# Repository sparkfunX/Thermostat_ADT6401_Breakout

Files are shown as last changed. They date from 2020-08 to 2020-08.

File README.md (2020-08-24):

SparkFun Auto-Digital Thermostat - ADT6401
=============================

ADT6401 (https://cdn.sparkfun.com/assets/parts/1/5/6/6/5/16772-Auto-Digital_Thermostat_-_ADT6401-01.jpg)

New from SparkX, the ADT6401 breakout board. This IC triggers alarm pin and LED when the temperature reading crosses a temperature trip point. Set the trip point easily using the SPDT switches included on the breakout.

SparkFun labored with love to design this board. Feel like supporting open-source hardware?
Buy a [board](https://www.sparkfun.com/) from SparkFun!

Repository Contents
-------------------

* **/Documents** - Datasheet for the ADT6401 IC.
* **/Hardware** - Eagle design files (.brd, .sch).
* **/Production** - Production panel files (.brd).

License Information
-------------------

This product is _**open source**_!

Please review the LICENSE.md file for license information.

If you have any questions or concerns regarding our licensing, please contact technical support on our [SparkFun Forum](https://www.sparkfun.com/viewforum.php?f=152).

Distributed as-is; no warranty is given.

- Your friends at SparkFun

_<COLLABORATION CREDIT>_

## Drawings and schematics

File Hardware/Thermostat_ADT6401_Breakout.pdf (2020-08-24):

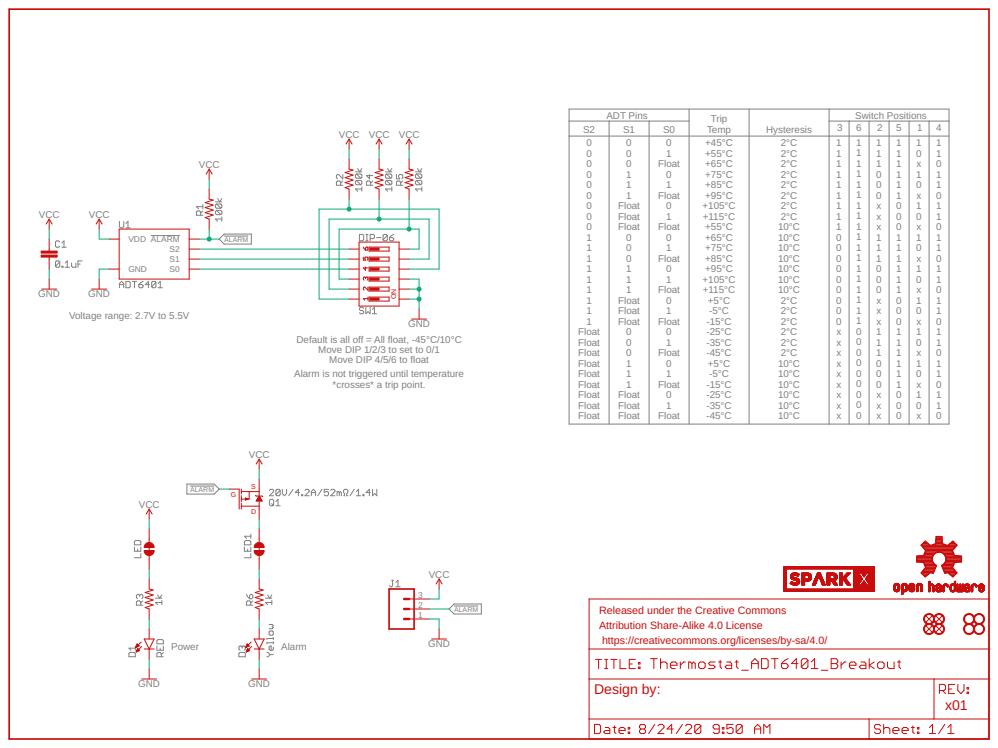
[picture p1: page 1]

ADT Pins | Trip Temp | Hysteresis
S2 | S1 | S0

Default is all off = All float, -45°C/10°C
Move DIP 1/2/3 to set to 0/1
Move DIP 4/5/6 to float

Alarm is not triggered until temperature

Released under the Creative Commons Attribution Share-Alike 4.0 License

https://creativecommons.org/licenses/by-sa/4.0/

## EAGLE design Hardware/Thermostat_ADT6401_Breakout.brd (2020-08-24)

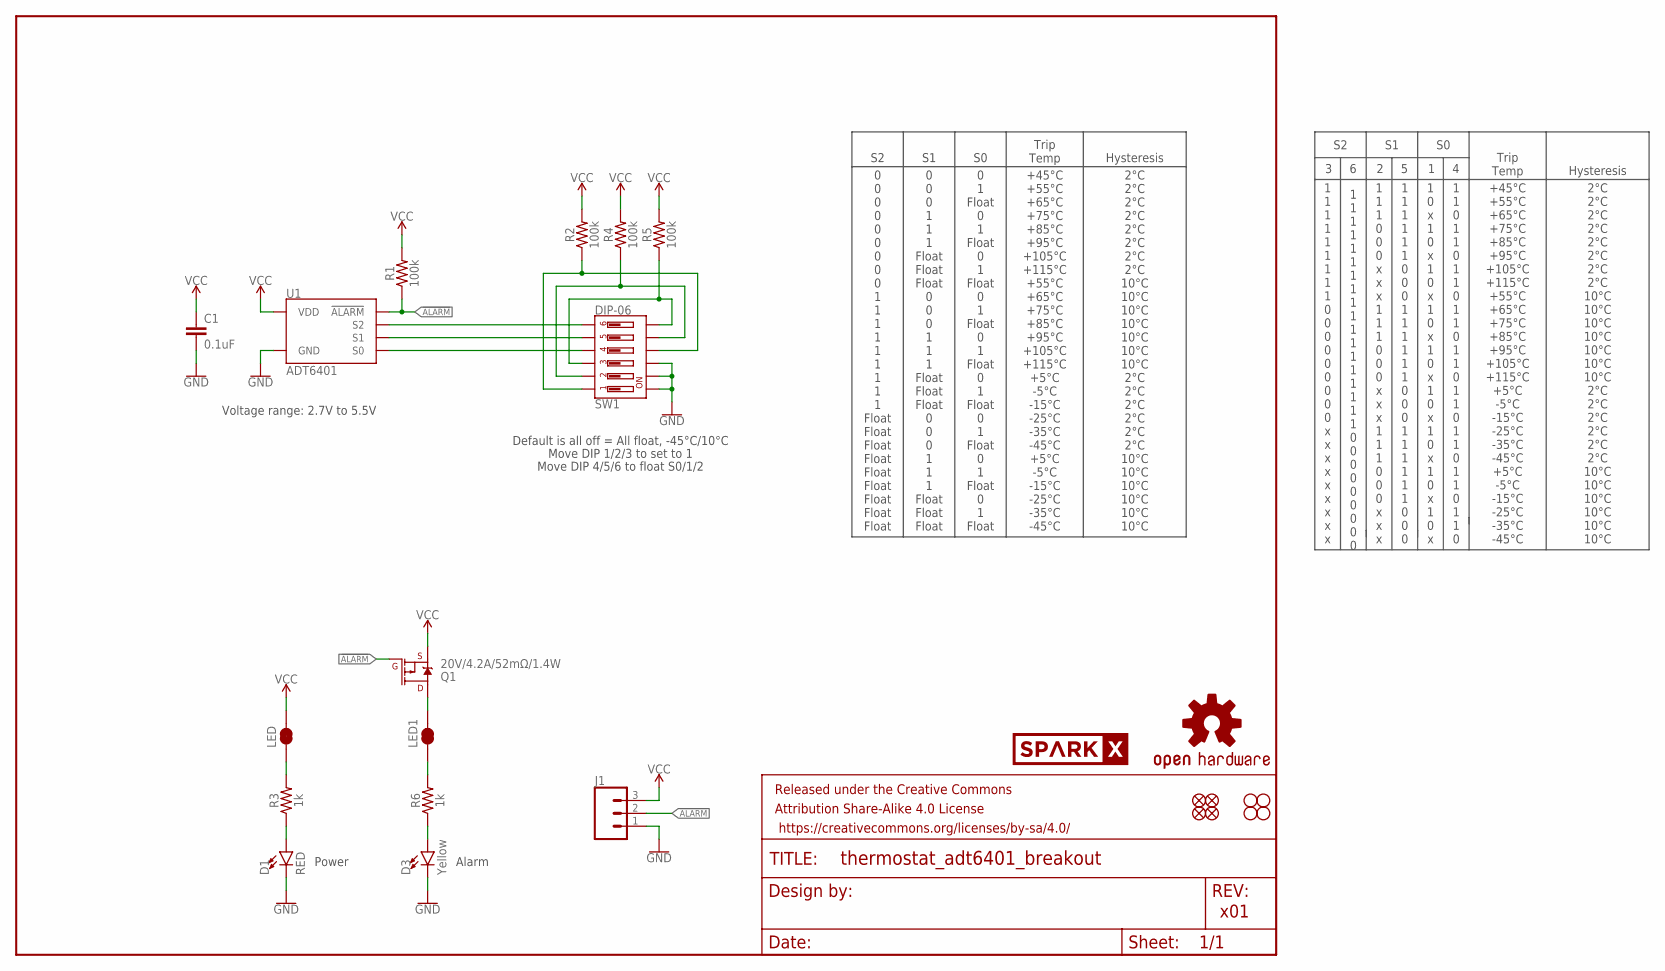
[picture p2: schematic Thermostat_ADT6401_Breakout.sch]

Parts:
C1: 0.1uF; 0603
D1: RED; LED-0603
D3: Yellow; LED-0603
FRAME1: FRAME-LETTER; CREATIVE_COMMONS
J1: CONN_031X03_NO_SILK; 1X03_NO_SILK
JP1, JP2, JP5, JP6: FIDUCIAL1X2; FIDUCIAL-1X2
JP3, JP4, JP8, JP9: STAND-OFF
LED, LED1: JUMPER-SMT_2_NC_TRACE_SILK; SMT-JUMPER_2_NC_TRACE_SILK
LOGO1: OSHW-LOGOMINI; OSHW-LOGO-MINI
Q1: 20V/4.2A/52mΩ/1.4W; SOT23-3
R1, R2, R4, R5: 100k; 0603
R3, R6: 1k; 0603
SW1: DIP-06; DIPSWITCH-06-SMD
U1: ADT6401; SOT23-6
U$1: SPARKX-LOGO4; SPARKX-MEDIUM

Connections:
!ALARM!: J1.2, Q1.1 (G), R1.1, U1.6 (!ALARM!)
GND: C1.2, D1.C, D3.C, J1.1, SW1.10, SW1.11, SW1.12, U1.5 (GND)
unnamed: D1.A, R3.1
unnamed: LED.1, R3.2
unnamed: LED1.2, Q1.3 (D)
unnamed: D3.A, R6.1
unnamed: LED1.1, R6.2
S0: SW1.4, U1.3 (S0)
S0_PU: R2.1, SW1.1, SW1.9
S1: SW1.5, U1.2 (S1)
S1_PU: R4.1, SW1.2, SW1.8
S2: SW1.6, U1.1 (S2)
S2_PU: R5.1, SW1.3, SW1.7
VCC: C1.1, J1.3, LED.2, Q1.2 (S), R1.2, R2.2, R4.2, R5.2, U1.4 (VDD)

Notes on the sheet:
x01
Power
Move DIP 4/5/6 to float S0/1/2
0 0 0 0 0 0 0 0 0 1 1 1 1 1 1 1 1 1 Float Float Float Float Float Float Float Float Float
+45°C +55°C +65°C +75°C +85°C +95°C +105°C +115°C +55°C +65°C +75°C +85°C +95°C +105°C +115°C +5°C -5°C -15°C -25°C -35°C -45°C +5°C -5°C -15°C -25°C -35°C -45°C
0 0 0 1 1 1 Float Float Float 0 0 0 1 1 1 Float Float Float 0 0 0 1 1 1 Float Float Float
0 1 Float 0 1 Float 0 1 Float 0 1 Float 0 1 Float 0 1 Float 0 1 Float 0 1 Float 0 1 Float
2°C 2°C 2°C 2°C 2°C 2°C 2°C 2°C 10°C 10°C 10°C 10°C 10°C 10°C 10°C 2°C 2°C 2°C 2°C 2°C 2°C 10°C 10°C 10°C 10°C 10°C 10°C
Trip Temp
Hysteresis
Move DIP 1/2/3 to set to 1
Default is all off = All float, -45°C/10°C
Alarm
Voltage range: 2.7V to 5.5V
1 1 0 1 1 0 1 1 0 1 1 0 1 1 0 1 1 0 1 1 0 1 1 0 1 1 0
1 0 x 1 0 x 1 0 x 1 0 x 1 0 x 1 0 x 1 0 x 1 0 x 1 0 x
1 1 1 1 1 1 0 0 0 1 1 1 1 1 1 0 0 0 1 1 1 1 1 1 0 0 0
1 1 1 0 0 0 x x x 1 1 1 0 0 0 x x x 1 1 1 0 0 0 x x x
1 1 1 1 1 1 1 1 1 1 1 1 1 1 1 1 1 1 0 0 0 0 0 0 0 0 0
1 1 1 1 1 1 1 1 1 0 0 0 0 0 0 0 0 0 x x x x x x x x x

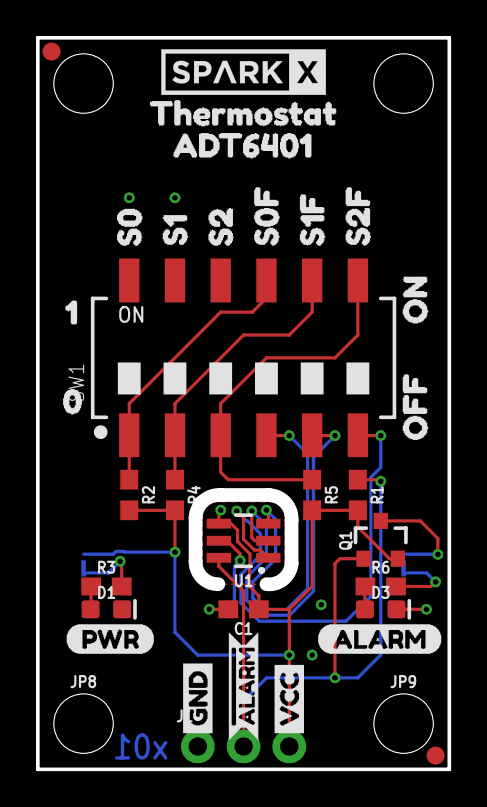
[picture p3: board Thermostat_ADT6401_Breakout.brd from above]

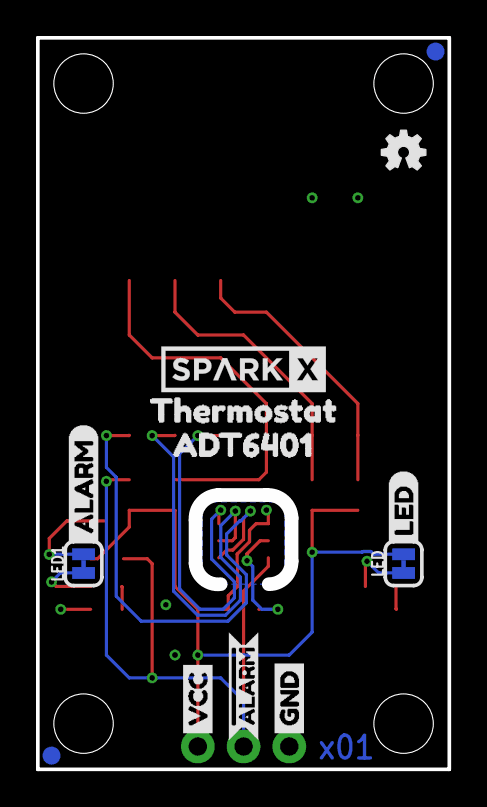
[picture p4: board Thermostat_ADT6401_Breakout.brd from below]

Board: 2 copper layers, 22.9 x 40.6 mm, 52 parts (13 on the bottom side), 14 nets.

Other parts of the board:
U$2: 01
U$3, U$15: #ALARM6
U$4, U$12: ADT64012
U$5, U$13: GND6
U$6: OFF3
U$7: ON2
U$8: 10
U$9, U$19: THERMOSTAT0
U$10: (PWR)
U$11, U$16: VCC5
U$14: S1F5
U$17: SPARKX-LOGO4; SPARKX-MEDIUM
U$18: ORDERING_INSTRUCTIONS
U$20: ALARM1
U$21: S2F7
U$22: S12
U$23: S23
U$24: S00
U$25: S0F1
U$26: LED0
U$27: ALARM2

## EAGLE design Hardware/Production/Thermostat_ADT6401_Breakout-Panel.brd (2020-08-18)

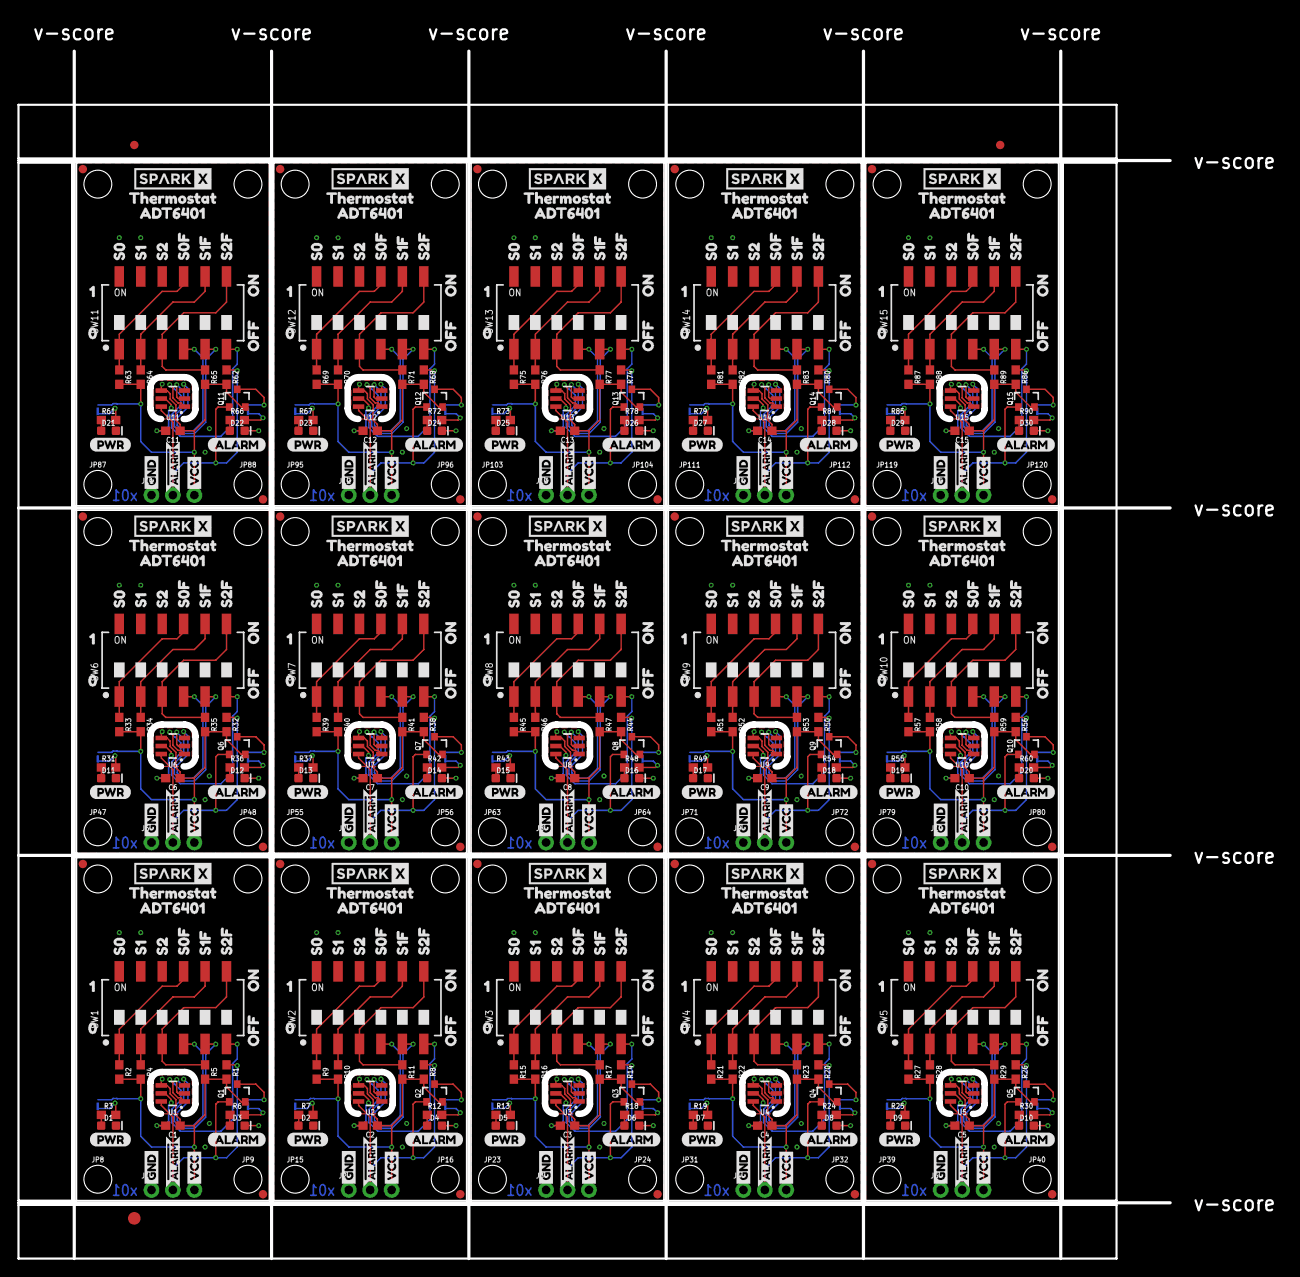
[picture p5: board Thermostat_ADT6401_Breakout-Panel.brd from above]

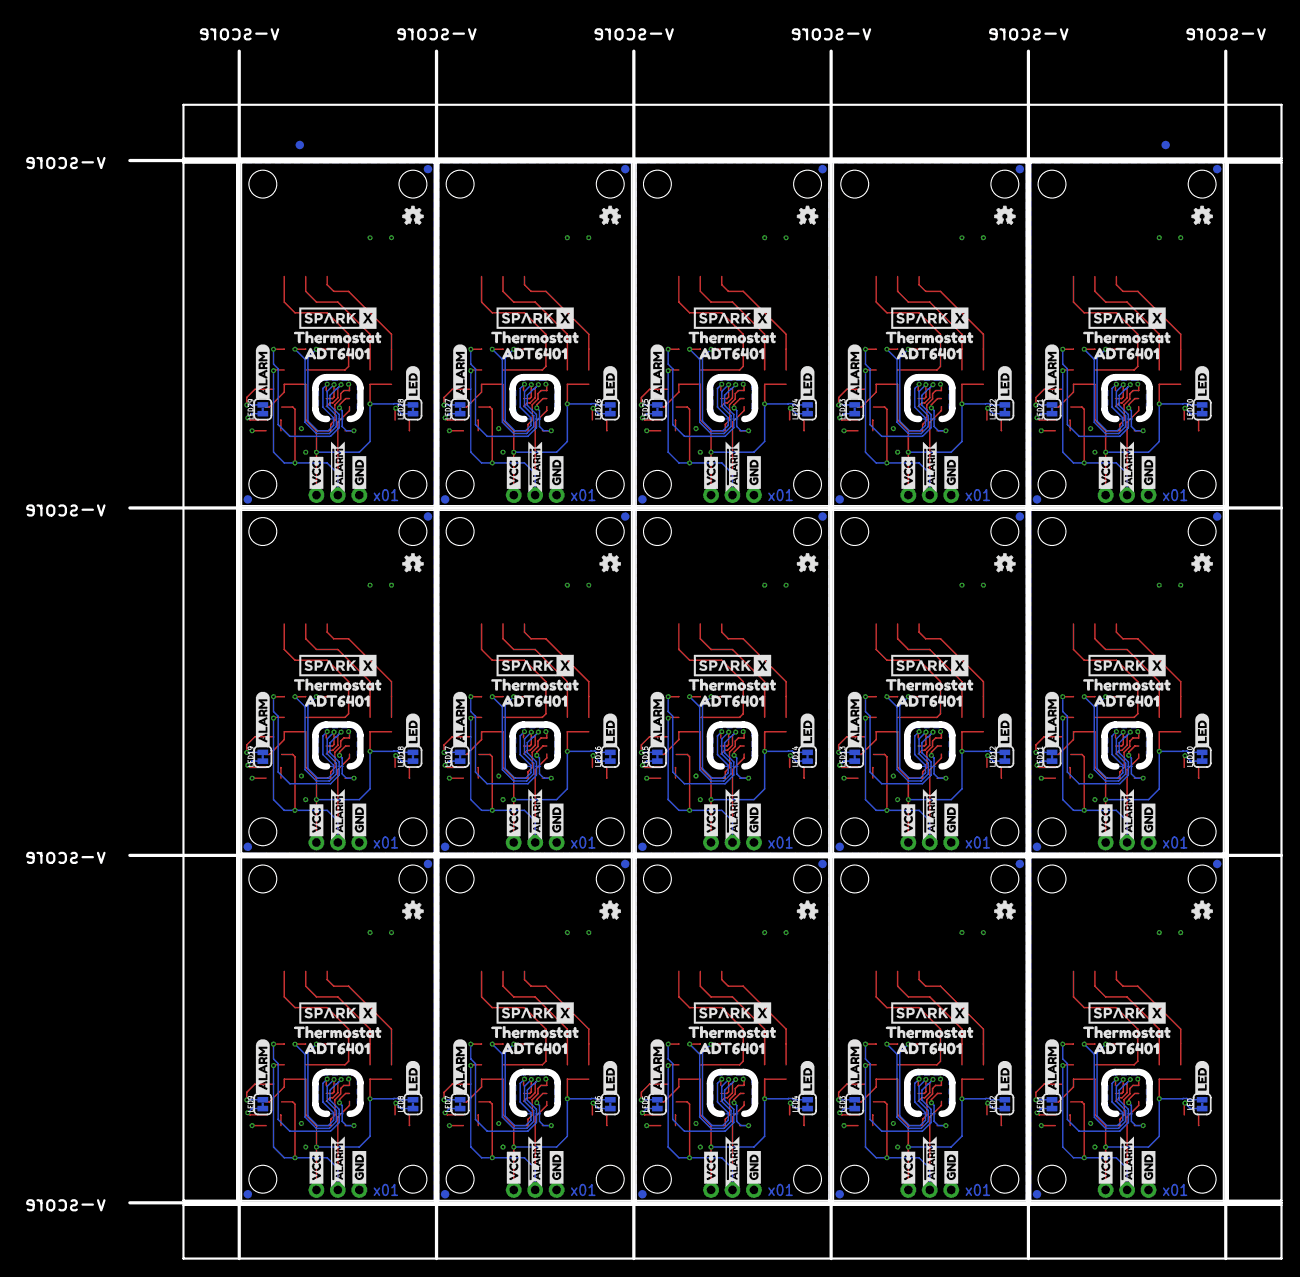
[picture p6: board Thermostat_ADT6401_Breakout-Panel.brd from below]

Board: 2 copper layers, 136.4 x 143.0 mm, 755 parts (197 on the bottom side), 210 nets.

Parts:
C1, C2, C3, C4, C5, C6, C7, C8, C9, C10, C11, C12, C13, C14, C15: 0.1uF; 0603
D1, D2, D5, D7, D9, D11, D13, D15, D17, D19, D21, D23, D25, D27, D29: RED; LED-0603
D3, D4, D6, D8, D10, D12, D14, D16, D18, D20, D22, D24, D26, D28, D30: Yellow; LED-0603
E$1, E$2, E$3, E$4: FIDUCIAL-1X2
E$5: FIDUCIAL-1.5X3
J1, J2, J3, J4, J5, J6, J7, J8, J9, J10, J11, J12, J13, J14, J15: 1X03_NO_SILK
JP1, JP2, JP5, JP6, JP11, JP12, JP13, JP14, JP19, JP20, JP21, JP22, JP27, JP28, JP29, JP30, JP35, JP36, JP37, JP38, JP43, JP44, JP45, JP46, JP51, JP52, JP53, JP54, JP59, JP60, JP61, JP62, JP67, JP68, JP69, JP70, JP75, JP76, JP77, JP78, JP83, JP84, JP85, JP86, JP91, JP92, JP93, JP94, JP99, JP100, JP101, JP102, JP107, JP108, JP109, JP110, JP115, JP116, JP117, JP118: FIDUCIAL1X2; FIDUCIAL-1X2
JP3, JP4, JP7, JP8, JP9, JP10, JP15, JP16, JP17, JP18, JP23, JP24, JP25, JP26, JP31, JP32, JP33, JP34, JP39, JP40, JP41, JP42, JP47, JP48, JP49, JP50, JP55, JP56, JP57, JP58, JP63, JP64, JP65, JP66, JP71, JP72, JP73, JP74, JP79, JP80, JP81, JP82, JP87, JP88, JP89, JP90, JP95, JP96, JP97, JP98, JP103, JP104, JP105, JP106, JP111, JP112, JP113, JP114, JP119, JP120: STAND-OFF
LED, LED1, LED2, LED3, LED4, LED5, LED6, LED7, LED8, LED9, LED10, LED11, LED12, LED13, LED14, LED15, LED16, LED17, LED18, LED19, LED20, LED21, LED22, LED23, LED24, LED25, LED26, LED27, LED28, LED29: SMT-JUMPER_2_NC_TRACE_SILK
LOGO1, LOGO2, LOGO3, LOGO4, LOGO5, LOGO6, LOGO7, LOGO8, LOGO9, LOGO10, LOGO11, LOGO12, LOGO13, LOGO14, LOGO15: OSHW-LOGOMINI; OSHW-LOGO-MINI
Q1, Q2, Q3, Q4, Q5, Q6, Q7, Q8, Q9, Q10, Q11, Q12, Q13, Q14, Q15: 20V/4.2A/52mΩ/1.4W; SOT23-3
R1, R2, R4, R5, R8, R9, R10, R11, R14, R15, R16, R17, R20, R21, R22, R23, R26, R27, R28, R29, R32, R33, R34, R35, R38, R39, R40, R41, R44, R45, R46, R47, R50, R51, R52, R53, R56, R57, R58, R59, R62, R63, R64, R65, R68, R69, R70, R71, R74, R75, R76, R77, R80, R81, R82, R83, R86, R87, R88, R89: 100k; 0603
R3, R6, R7, R12, R13, R18, R19, R24, R25, R30, R31, R36, R37, R42, R43, R48, R49, R54, R55, R60, R61, R66, R67, R72, R73, R78, R79, R84, R85, R90: 1k; 0603
SW1, SW2, SW3, SW4, SW5, SW6, SW7, SW8, SW9, SW10, SW11, SW12, SW13, SW14, SW15: DIP-06; DIPSWITCH-06-SMD
U1, U2, U3, U4, U5, U6, U7, U8, U9, U10, U11, U12, U13, U14, U15: ADT6401; SOT23-6
U$1, U$17, U$18, U$36, U$53, U$62, U$79, U$88, U$105, U$114, U$131, U$140, U$157, U$166, U$183, U$192, U$209, U$218, U$235, U$244, U$261, U$270, U$287, U$296, U$313, U$322, U$339, U$348, U$365, U$374: SPARKX-LOGO4; SPARKX-MEDIUM
U$2, U$40, U$66, U$92, U$118, U$144, U$170, U$196, U$222, U$248, U$274, U$300, U$326, U$352, U$378: 01
U$3, U$15, U$38, U$39, U$64, U$65, U$90, U$91, U$116, U$117, U$142, U$143, U$168, U$169, U$194, U$195, U$220, U$221, U$246, U$247, U$272, U$273, U$298, U$299, U$324, U$325, U$350, U$351, U$376, U$377: #ALARM6
U$4, U$12, U$49, U$50, U$75, U$76, U$101, U$102, U$127, U$128, U$153, U$154, U$179, U$180, U$205, U$206, U$231, U$232, U$257, U$258, U$283, U$284, U$309, U$310, U$335, U$336, U$361, U$362, U$387, U$388: ADT64012
U$5, U$13, U$29, U$34, U$55, U$60, U$81, U$86, U$107, U$112, U$133, U$138, U$159, U$164, U$185, U$190, U$211, U$216, U$237, U$242, U$263, U$268, U$289, U$294, U$315, U$320, U$341, U$346, U$367, U$372: GND6
U$6, U$30, U$56, U$82, U$108, U$134, U$160, U$186, U$212, U$238, U$264, U$290, U$316, U$342, U$368: OFF3
U$7, U$31, U$57, U$83, U$109, U$135, U$161, U$187, U$213, U$239, U$265, U$291, U$317, U$343, U$369: ON2
U$8, U$41, U$67, U$93, U$119, U$145, U$171, U$197, U$223, U$249, U$275, U$301, U$327, U$353, U$379: 10
U$9, U$19, U$32, U$37, U$58, U$63, U$84, U$89, U$110, U$115, U$136, U$141, U$162, U$167, U$188, U$193, U$214, U$219, U$240, U$245, U$266, U$271, U$292, U$297, U$318, U$323, U$344, U$349, U$370, U$375: THERMOSTAT0
U$10, U$28, U$54, U$80, U$106, U$132, U$158, U$184, U$210, U$236, U$262, U$288, U$314, U$340, U$366: (PWR)
U$11, U$16, U$33, U$35, U$59, U$61, U$85, U$87, U$111, U$113, U$137, U$139, U$163, U$165, U$189, U$191, U$215, U$217, U$241, U$243, U$267, U$269, U$293, U$295, U$319, U$321, U$345, U$347, U$371, U$373: VCC5
U$14, U$42, U$68, U$94, U$120, U$146, U$172, U$198, U$224, U$250, U$276, U$302, U$328, U$354, U$380: S1F5
U$20, U$51, U$77, U$103, U$129, U$155, U$181, U$207, U$233, U$259, U$285, U$311, U$337, U$363, U$389: ALARM1
U$21, U$43, U$69, U$95, U$121, U$147, U$173, U$199, U$225, U$251, U$277, U$303, U$329, U$355, U$381: S2F7
U$22, U$44, U$70, U$96, U$122, U$148, U$174, U$200, U$226, U$252, U$278, U$304, U$330, U$356, U$382: S12
U$23, U$45, U$71, U$97, U$123, U$149, U$175, U$201, U$227, U$253, U$279, U$305, U$331, U$357, U$383: S23
U$24, U$46, U$72, U$98, U$124, U$150, U$176, U$202, U$228, U$254, U$280, U$306, U$332, U$358, U$384: S00
U$25, U$47, U$73, U$99, U$125, U$151, U$177, U$203, U$229, U$255, U$281, U$307, U$333, U$359, U$385: S0F1
U$26, U$52, U$78, U$104, U$130, U$156, U$182, U$208, U$234, U$260, U$286, U$312, U$338, U$364, U$390: LED0
U$27, U$48, U$74, U$100, U$126, U$152, U$178, U$204, U$230, U$256, U$282, U$308, U$334, U$360, U$386: ALARM2

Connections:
!ALARM!: J1.2, Q1.1, R1.1, U1.6
!ALARM!1: J2.2, Q2.1, R8.1, U2.6
!ALARM!2: J3.2, Q3.1, R14.1, U3.6
!ALARM!3: J4.2, Q4.1, R20.1, U4.6
!ALARM!4: J5.2, Q5.1, R26.1, U5.6
!ALARM!5: J6.2, Q6.1, R32.1, U6.6
!ALARM!6: J7.2, Q7.1, R38.1, U7.6
!ALARM!7: J8.2, Q8.1, R44.1, U8.6
!ALARM!8: J9.2, Q9.1, R50.1, U9.6
!ALARM!9: J10.2, Q10.1, R56.1, U10.6
!ALARM!10: J11.2, Q11.1, R62.1, U11.6
!ALARM!11: J12.2, Q12.1, R68.1, U12.6
!ALARM!12: J13.2, Q13.1, R74.1, U13.6
!ALARM!13: J14.2, Q14.1, R80.1, U14.6
!ALARM!14: J15.2, Q15.1, R86.1, U15.6
GND: C1.2, D1.C, D3.C, J1.1, SW1.10, SW1.11, SW1.12, U1.5
GND1: C2.2, D2.C, D4.C, J2.1, SW2.10, SW2.11, SW2.12, U2.5
GND2: C3.2, D5.C, D6.C, J3.1, SW3.10, SW3.11, SW3.12, U3.5
GND3: C4.2, D7.C, D8.C, J4.1, SW4.10, SW4.11, SW4.12, U4.5
GND4: C5.2, D9.C, D10.C, J5.1, SW5.10, SW5.11, SW5.12, U5.5
GND5: C6.2, D11.C, D12.C, J6.1, SW6.10, SW6.11, SW6.12, U6.5
GND6: C7.2, D13.C, D14.C, J7.1, SW7.10, SW7.11, SW7.12, U7.5
GND7: C8.2, D15.C, D16.C, J8.1, SW8.10, SW8.11, SW8.12, U8.5
GND8: C9.2, D17.C, D18.C, J9.1, SW9.10, SW9.11, SW9.12, U9.5
GND9: C10.2, D19.C, D20.C, J10.1, SW10.10, SW10.11, SW10.12, U10.5
GND10: C11.2, D21.C, D22.C, J11.1, SW11.10, SW11.11, SW11.12, U11.5
GND11: C12.2, D23.C, D24.C, J12.1, SW12.10, SW12.11, SW12.12, U12.5
GND12: C13.2, D25.C, D26.C, J13.1, SW13.10, SW13.11, SW13.12, U13.5
GND13: C14.2, D27.C, D28.C, J14.1, SW14.10, SW14.11, SW14.12, U14.5
GND14: C15.2, D29.C, D30.C, J15.1, SW15.10, SW15.11, SW15.12, U15.5
unnamed: D2.A, R7.1
unnamed: LED2.1, R7.2
unnamed: D1.A, R3.1
unnamed: LED.1, R3.2
unnamed: LED1.2, Q1.3
unnamed: D3.A, R6.1
unnamed: LED1.1, R6.2
unnamed: LED3.2, Q2.3
unnamed: D4.A, R12.1
unnamed: LED3.1, R12.2
unnamed: D5.A, R13.1
unnamed: LED4.1, R13.2
unnamed: LED5.2, Q3.3
unnamed: D6.A, R18.1
unnamed: LED5.1, R18.2
unnamed: D7.A, R19.1
unnamed: LED6.1, R19.2
unnamed: LED7.2, Q4.3
unnamed: D8.A, R24.1
unnamed: LED7.1, R24.2
unnamed: D9.A, R25.1
unnamed: LED8.1, R25.2
unnamed: LED9.2, Q5.3
unnamed: D10.A, R30.1
unnamed: LED9.1, R30.2
unnamed: D11.A, R31.1
unnamed: LED10.1, R31.2
unnamed: LED11.2, Q6.3
unnamed: D12.A, R36.1
unnamed: LED11.1, R36.2
unnamed: D13.A, R37.1
unnamed: LED12.1, R37.2
unnamed: LED13.2, Q7.3
unnamed: D14.A, R42.1
unnamed: LED13.1, R42.2
unnamed: D15.A, R43.1
unnamed: LED14.1, R43.2
unnamed: LED15.2, Q8.3
unnamed: D16.A, R48.1
unnamed: LED15.1, R48.2
unnamed: D17.A, R49.1
unnamed: LED16.1, R49.2
unnamed: LED17.2, Q9.3
unnamed: D18.A, R54.1
unnamed: LED17.1, R54.2
unnamed: D19.A, R55.1
unnamed: LED18.1, R55.2
unnamed: LED19.2, Q10.3
unnamed: D20.A, R60.1
unnamed: LED19.1, R60.2
unnamed: D21.A, R61.1
unnamed: LED20.1, R61.2
unnamed: LED21.2, Q11.3
unnamed: D22.A, R66.1
unnamed: LED21.1, R66.2
unnamed: D23.A, R67.1
unnamed: LED22.1, R67.2
unnamed: LED23.2, Q12.3
unnamed: D24.A, R72.1
unnamed: LED23.1, R72.2
unnamed: D25.A, R73.1
unnamed: LED24.1, R73.2
unnamed: LED25.2, Q13.3
unnamed: D26.A, R78.1
unnamed: LED25.1, R78.2
unnamed: D27.A, R79.1
unnamed: LED26.1, R79.2
unnamed: LED27.2, Q14.3
unnamed: D28.A, R84.1
unnamed: LED27.1, R84.2
unnamed: D29.A, R85.1
unnamed: LED28.1, R85.2
unnamed: LED29.2, Q15.3
unnamed: D30.A, R90.1
unnamed: LED29.1, R90.2
S0: SW1.4, U1.3
S0_PU: R2.1, SW1.1, SW1.9
S0_PU1: R9.1, SW2.1, SW2.9
S0_PU2: R15.1, SW3.1, SW3.9
S0_PU3: R21.1, SW4.1, SW4.9
S0_PU4: R27.1, SW5.1, SW5.9
S0_PU5: R33.1, SW6.1, SW6.9
S0_PU6: R39.1, SW7.1, SW7.9
S0_PU7: R45.1, SW8.1, SW8.9
S0_PU8: R51.1, SW9.1, SW9.9
S0_PU9: R57.1, SW10.1, SW10.9
S0_PU10: R63.1, SW11.1, SW11.9
S0_PU11: R69.1, SW12.1, SW12.9
S0_PU12: R75.1, SW13.1, SW13.9
S0_PU13: R81.1, SW14.1, SW14.9
S0_PU14: R87.1, SW15.1, SW15.9
S1: SW1.5, U1.2
S1_PU: R4.1, SW1.2, SW1.8
S1_PU1: R10.1, SW2.2, SW2.8
S1_PU2: R16.1, SW3.2, SW3.8
S1_PU3: R22.1, SW4.2, SW4.8
S1_PU4: R28.1, SW5.2, SW5.8
S1_PU5: R34.1, SW6.2, SW6.8
S1_PU6: R40.1, SW7.2, SW7.8
S1_PU7: R46.1, SW8.2, SW8.8
S1_PU8: R52.1, SW9.2, SW9.8
S1_PU9: R58.1, SW10.2, SW10.8
S1_PU10: R64.1, SW11.2, SW11.8
S1_PU11: R70.1, SW12.2, SW12.8
S1_PU12: R76.1, SW13.2, SW13.8
S1_PU13: R82.1, SW14.2, SW14.8
S1_PU14: R88.1, SW15.2, SW15.8
S2: SW1.6, U1.1
S2_PU: R5.1, SW1.3, SW1.7
S2_PU1: R11.1, SW2.3, SW2.7
S2_PU2: R17.1, SW3.3, SW3.7
S2_PU3: R23.1, SW4.3, SW4.7
S2_PU4: R29.1, SW5.3, SW5.7
S2_PU5: R35.1, SW6.3, SW6.7
S2_PU6: R41.1, SW7.3, SW7.7
S2_PU7: R47.1, SW8.3, SW8.7
S2_PU8: R53.1, SW9.3, SW9.7
S2_PU9: R59.1, SW10.3, SW10.7
S2_PU10: R65.1, SW11.3, SW11.7
S2_PU11: R71.1, SW12.3, SW12.7
S2_PU12: R77.1, SW13.3, SW13.7
S2_PU13: R83.1, SW14.3, SW14.7
S2_PU14: R89.1, SW15.3, SW15.7
S3: SW2.4, U2.3
S4: SW2.5, U2.2
S5: SW2.6, U2.1
S6: SW3.4, U3.3
S7: SW3.5, U3.2
S8: SW3.6, U3.1
S9: SW4.4, U4.3
S10: SW4.5, U4.2
S11: SW4.6, U4.1
S12: SW5.4, U5.3
S13: SW5.5, U5.2
S14: SW5.6, U5.1
S15: SW6.4, U6.3
S16: SW6.5, U6.2
S17: SW6.6, U6.1
S18: SW7.4, U7.3
S19: SW7.5, U7.2
S20: SW7.6, U7.1
S21: SW8.4, U8.3
S22: SW8.5, U8.2
S23: SW8.6, U8.1
S24: SW9.4, U9.3
S25: SW9.5, U9.2
S26: SW9.6, U9.1
S27: SW10.4, U10.3
S28: SW10.5, U10.2
S29: SW10.6, U10.1
S30: SW11.4, U11.3
S31: SW11.5, U11.2
S32: SW11.6, U11.1
S33: SW12.4, U12.3
S34: SW12.5, U12.2
S35: SW12.6, U12.1
S36: SW13.4, U13.3
S37: SW13.5, U13.2
S38: SW13.6, U13.1
S39: SW14.4, U14.3
S40: SW14.5, U14.2
S41: SW14.6, U14.1
S42: SW15.4, U15.3
S43: SW15.5, U15.2
S44: SW15.6, U15.1
VCC: C1.1, J1.3, LED.2, Q1.2, R1.2, R2.2, R4.2, R5.2, U1.4
VCC1: C2.1, J2.3, LED2.2, Q2.2, R8.2, R9.2, R10.2, R11.2, U2.4
VCC2: C3.1, J3.3, LED4.2, Q3.2, R14.2, R15.2, R16.2, R17.2, U3.4
VCC3: C4.1, J4.3, LED6.2, Q4.2, R20.2, R21.2, R22.2, R23.2, U4.4
VCC4: C5.1, J5.3, LED8.2, Q5.2, R26.2, R27.2, R28.2, R29.2, U5.4
VCC5: C6.1, J6.3, LED10.2, Q6.2, R32.2, R33.2, R34.2, R35.2, U6.4
VCC6: C7.1, J7.3, LED12.2, Q7.2, R38.2, R39.2, R40.2, R41.2, U7.4
VCC7: C8.1, J8.3, LED14.2, Q8.2, R44.2, R45.2, R46.2, R47.2, U8.4
VCC8: C9.1, J9.3, LED16.2, Q9.2, R50.2, R51.2, R52.2, R53.2, U9.4
VCC9: C10.1, J10.3, LED18.2, Q10.2, R56.2, R57.2, R58.2, R59.2, U10.4
VCC10: C11.1, J11.3, LED20.2, Q11.2, R62.2, R63.2, R64.2, R65.2, U11.4
VCC11: C12.1, J12.3, LED22.2, Q12.2, R68.2, R69.2, R70.2, R71.2, U12.4
VCC12: C13.1, J13.3, LED24.2, Q13.2, R74.2, R75.2, R76.2, R77.2, U13.4
VCC13: C14.1, J14.3, LED26.2, Q14.2, R80.2, R81.2, R82.2, R83.2, U14.4
VCC14: C15.1, J15.3, LED28.2, Q15.2, R86.2, R87.2, R88.2, R89.2, U15.4

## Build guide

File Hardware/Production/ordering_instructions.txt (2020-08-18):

panel size, 131x130mm
PCB thickness, 0.8mm
number of layers, 2
soldermask color, Black
silkscreen color, White
oz copper, 1oz
finish, HASL lead free
stencils, top+bottom
pcs per panel, 15
min trace width, 0.1778mm / 0.0070in
min drill size, 0.3048mm / 0.0120in

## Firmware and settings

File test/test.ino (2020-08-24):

#define PIN2 2

int val = 0;
void setup() {
  Serial.begin(115200);
  Serial.println("ADT6401 Breakout Test");
  pinMode(PIN2, INPUT);
}

void loop() {
  val = digitalRead(PIN2);
  if (val == false){
    digitalWrite(LED_BUILTIN, HIGH);
    Serial.println("ALARM!");
  } else {
    digitalWrite(LED_BUILTIN, LOW); 
    Serial.println("Alarm not triggered");
  }
}

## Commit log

2020-08-20 Add voltage range
2020-08-24 Update SPDT chart pt 2
    [Thermostat_ADT6401_Breakout.brd, Thermostat_ADT6401_Breakout.sch]
2020-08-24 Combine switches into chart. Add ignore. Remove old files.
    [Thermostat_ADT6401_Breakout.sch]

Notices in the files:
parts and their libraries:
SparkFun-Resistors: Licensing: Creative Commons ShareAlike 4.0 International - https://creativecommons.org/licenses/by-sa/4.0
